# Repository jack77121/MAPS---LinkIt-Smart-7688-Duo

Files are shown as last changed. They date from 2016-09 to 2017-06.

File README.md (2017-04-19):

# Micro Air Pollution Sensing

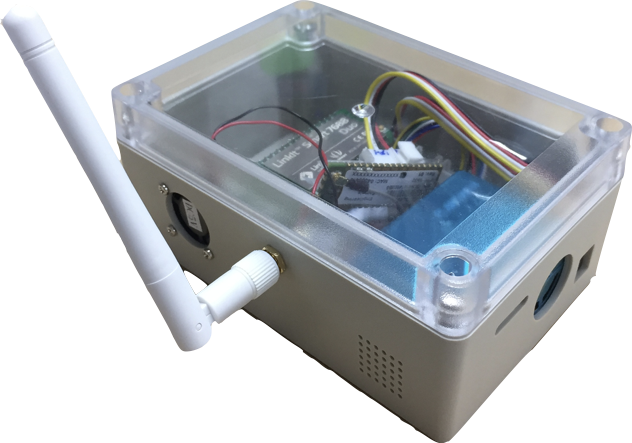
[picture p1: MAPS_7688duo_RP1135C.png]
Image of appearance


MAPS v5.1 appearance

## Story
**M**icro **A**ir **P**ollution **S**ensing - MAPS

Air pollution is a hot topic in recent years, especially - **Particulate Matter**. Traditional sensing method, we can only depend on professional sensors/devices, with large volume, heave weight and insanity price.
Thanks to the technology, now we could build our own air pollution sensing station, with micro volume, light weight and the price is affordable :). With MAPS, you can sense air pollution any where, any time by yourself, you can also give it a battery module to increase its mobility!

For more air pollution sensing project, you can visit [LASS facebook](https://www.facebook.com/groups/1607718702812067/) and [LASS github](https://github.com/LinkItONEDevGroup/LASS), we are makers who sense anything in our environment!

## Hardware & Sensors
Module     			 |	Description
---------------------|--------------
LinkIt Smart 7688 Duo|Mainboard
G5 (pms5003)			 |Particalute matter (PM)
BME280       			 |Temperature, humidity & Air pressure
SHT25					 |Temperature & humidity (optional)

p.s SHT25 is for device temperature, humidity monitoring and future calibration usage, MAPS is be still full functional without it.

## PCB layout & dimensions
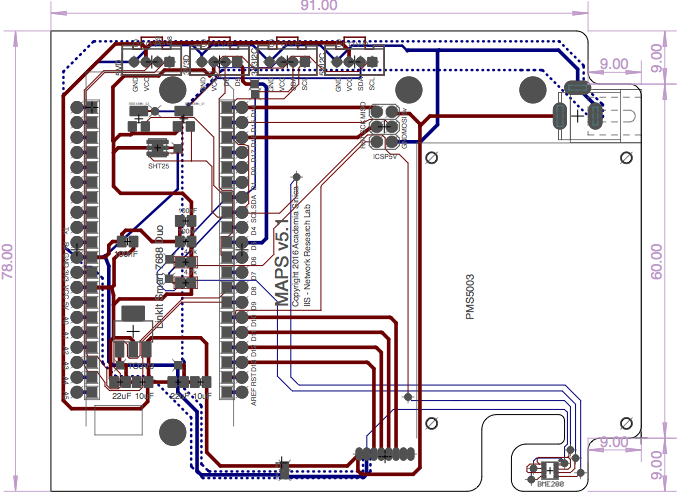
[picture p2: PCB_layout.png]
Image of pcb layout


(unit: mm)

## Installing
### Instrution
MAPS use both MT7688AN (MPU) and ATmega32U4 (MCU) onboard to complete its jobs. They communicate through UART (in this project). 

ATmega32U4 is reponsible for sensors data collection.( and data boardcasting through LPWAN, if you use LoRa.)

There is an OpenWrt Linux OS running on 7688 duo, so MT7688AN is capable for multiple jobs, its main task is data publishing through MQTT to the backend server, others like time sync, program update OTA and user preference setting (wifi, manual GPS) are its routine.

Installation will have two parts, first part is about the MCU program (arduino), and second part are the scripts for MPU.

p.s scripts for MPU are still in progress, will be update ASAP.

Below is the installing instruction about 
### MCU program (arduino)
1. You can download Arduino IDE [here](https://www.arduino.cc/en/Main/Software).
2. Put all folders in `library` into your arduino `libraries` folder. [Tutorial](https://www.arduino.cc/en/Guide/Libraries#toc5)
3. Use Arduino IDE to upload the code: `linkit_7688_duo_lora.ino`. [Tutorial](https://www.arduino.cc/en/Guide/HowtoUpload)

p.s `linkit_7688_duo_lora.ino` need to be in a same name folder, in this project, called `linkit_7688_duo_lora`. If you don't do let, the Arduino app will still ask you to make one. 

### MPU scripts (python + ash)
(Continue updating...)

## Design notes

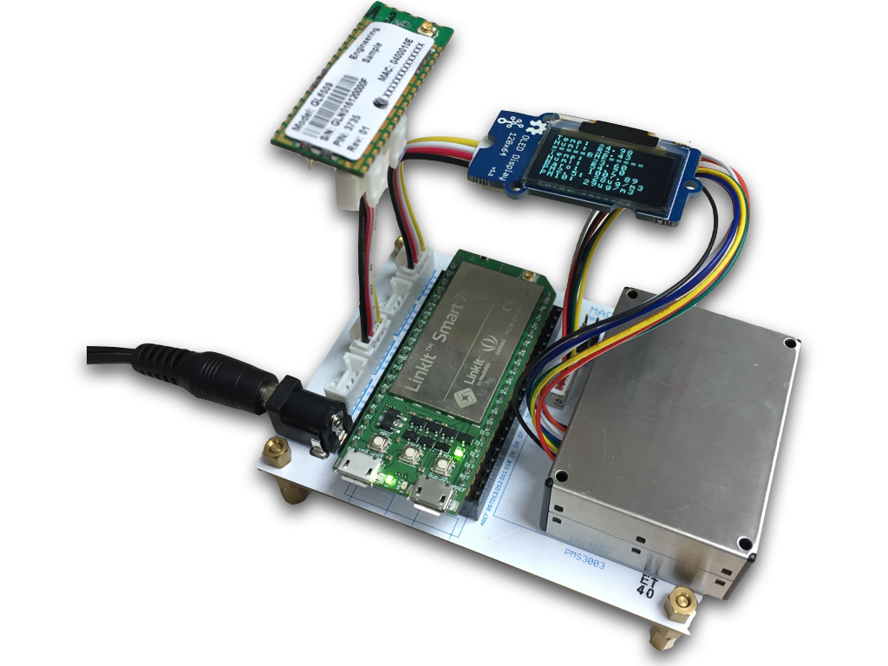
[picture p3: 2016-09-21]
MAPS_7688duo_appearance.png

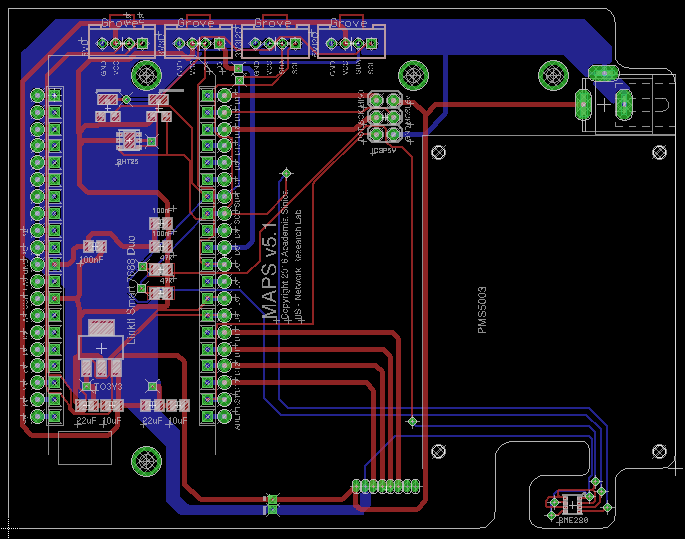
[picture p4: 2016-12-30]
linkit_smart7688_duo_extendboard/maps_board.png

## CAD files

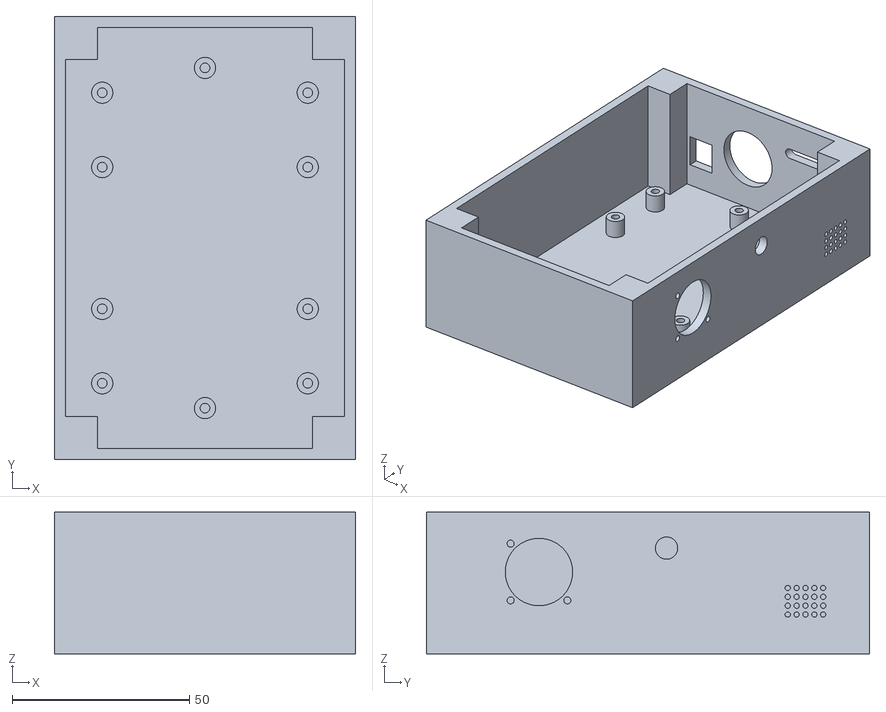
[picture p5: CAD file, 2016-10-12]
linkit_smart7688_duo_extendboard/RP1135C_ piercing_box.stl
85.0 x 125.0 x 40.0

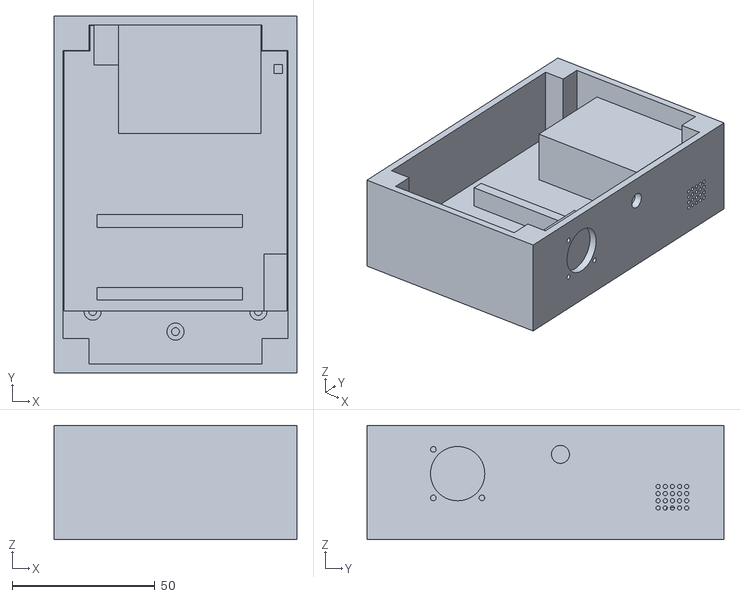
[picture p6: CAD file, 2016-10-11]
linkit_smart7688_duo_extendboard/RP1135C_ piercing.stl
85.0 x 125.0 x 40.0

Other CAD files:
linkit_smart7688_duo_extendboard/RP1135C_ piercing.3dm

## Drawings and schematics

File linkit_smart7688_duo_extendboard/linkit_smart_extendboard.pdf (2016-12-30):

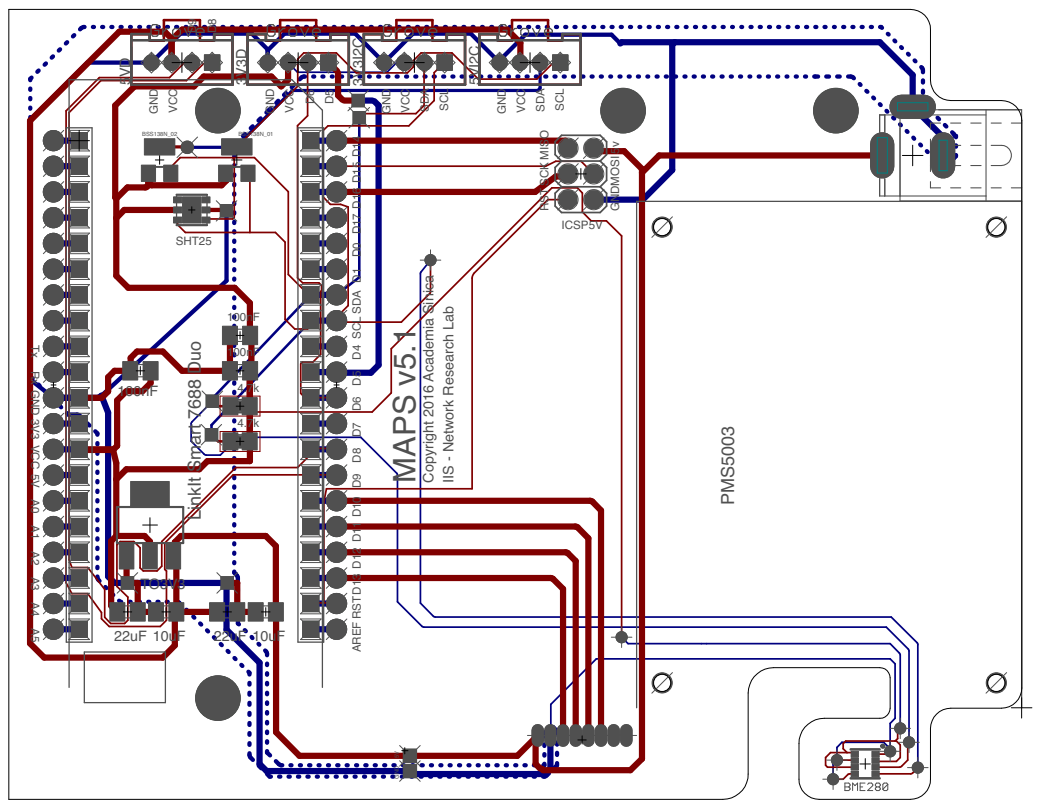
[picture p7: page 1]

VCC GND VCC GND SDA SCL VCC GND VCC GND SDA SCL 5V GND MAPS v5.1 Copyright 2016 Academia Sinica D5 D6 D8 D9 D14 D15 D16 D17 D0 D1 SDA SCL D4 D5 D6 D7 D8 D9 D10 D11 D12 D13 RST AREAF5 A4 A3 A2 A1 A0 5V VCC 3V3 GND Rx Tx 5v MOSI GND RST SCK MISO SHT25 IIS - Network Research Lab 3V3D 3V3I2C 5VD 5VI2C TO3V3 LinkIt Smart 7688 Duo ICSP5V BSS138N_02 BSS138N_01 PMS5003 22uF 10uF 22uF 10uF 100nF 100nF 100nF 4.7k 4.7k

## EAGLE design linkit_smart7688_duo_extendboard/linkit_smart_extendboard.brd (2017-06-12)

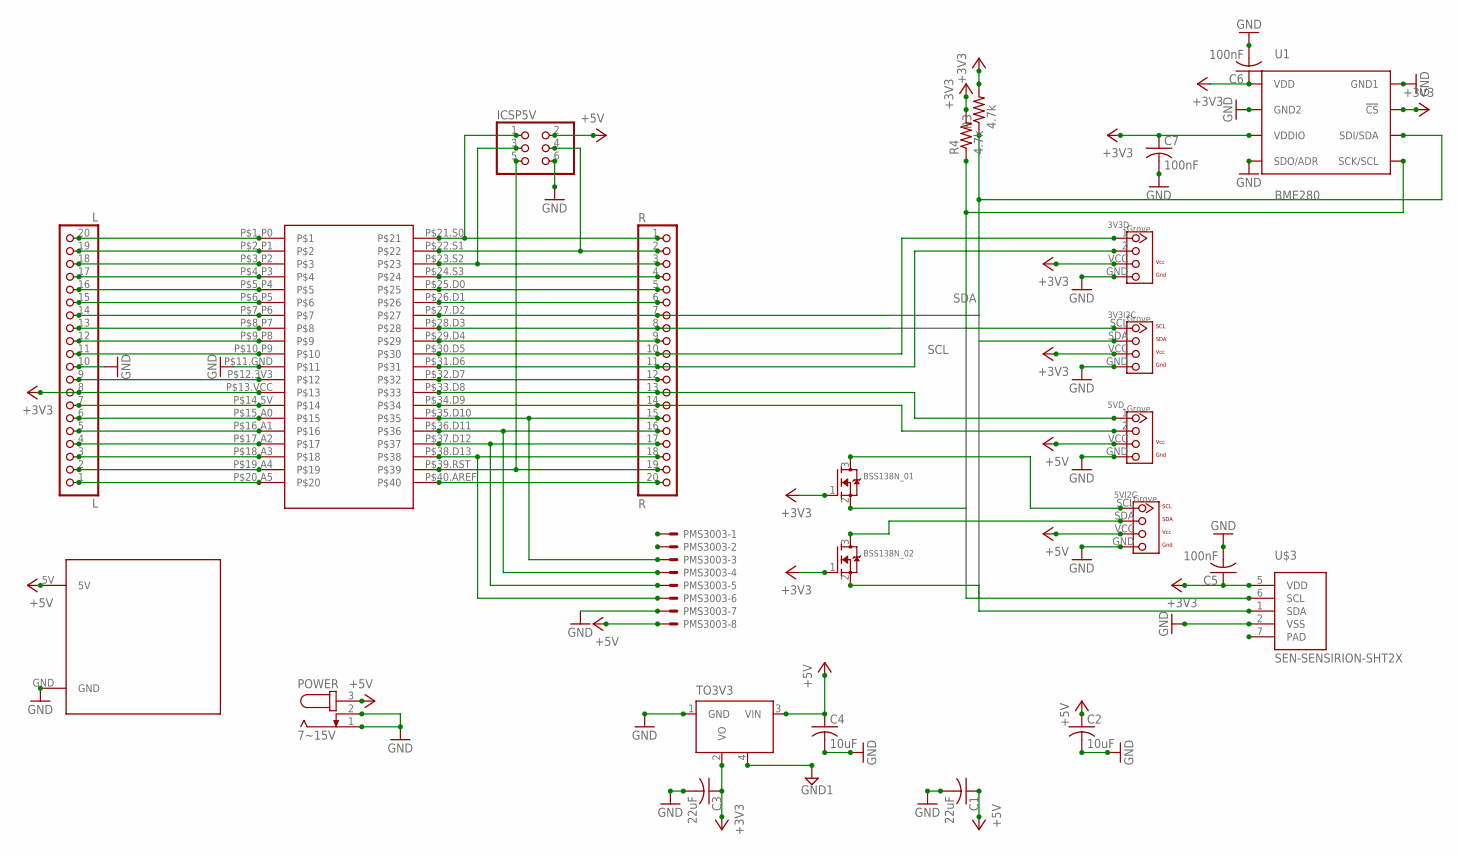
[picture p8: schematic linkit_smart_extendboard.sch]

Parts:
3V3D, 3V3I2C, 5VD, 5VI2C: TWIG-4P-2.0-2.0; 4P-2.0
BSS138N_01, BSS138N_02: MOSFET-NWAVE; SOT23-W
C1, C3: 22uF; C0805K
C2, C4: 10uF; C0805K
C5, C6, C7: 100nF; C0805K
ICSP5V: PINHD-2X3; 2X03
L: L; 1X20-BIG
PMS3003: 53047-08
POWER: 7~15V; SPC4077
R: R; 1X20-BIG
R3, R4: 4.7k; R0805
TO3V3: LM2936MP-3.0; SOT223
U1: BME280; BME280_LGA
U$1: LINKIT7688
U$3: SEN-SENSIRION-SHT2X
U$4: PIN2MM

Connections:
+3V3: 3V3D.VCC (3), 3V3I2C.VCC (3), BSS138N_01.1 (G), BSS138N_02.1 (G), C3.1, C5.1, C6.1, C7.1, L.8, R3.2, R4.2, TO3V3.2 (VO), U1.P$2 (!CS), U1.P$6 (VDDIO), U1.P$8 (VDD), U$1.P$13.VCC, U$3.5 (VDD)
+5V: 5VD.VCC (3), 5VI2C.VCC (3), C1.1, C2.1, C4.1, ICSP5V.2, PMS3003.8, POWER.3, TO3V3.3 (VIN), U$4.5V
GND: 3V3D.GND (4), 3V3I2C.GND (4), 5VD.GND (4), 5VI2C.GND (4), C1.2, C2.2, C3.2, C4.2, C5.2, C6.2, C7.2, ICSP5V.6, L.10, PMS3003.7, POWER.1, POWER.2, TO3V3.1 (GND), U1.P$1 (GND1), U1.P$5 (SDO/ADR), U1.P$7 (GND2), U$1.P$11.GND, U$3.2 (VSS), U$4.GND
GND1: TO3V3.4 (HS)
unnamed: L.9, U$1.P$12.3V3
unnamed: PMS3003.3, R.15, U$1.P$35.D10
unnamed: L.7, U$1.P$14.5V
unnamed: L.6, U$1.P$15.A0
unnamed: L.5, U$1.P$16.A1
unnamed: L.4, U$1.P$17.A2
unnamed: L.3, U$1.P$18.A3
unnamed: L.2, U$1.P$19.A4
unnamed: L.1, U$1.P$20.A5
unnamed: 3V3D.1, R.10, U$1.P$30.D5
unnamed: L.19, U$1.P$2.P1
unnamed: L.18, U$1.P$3.P2
unnamed: L.17, U$1.P$4.P3
unnamed: L.16, U$1.P$5.P4
unnamed: L.15, U$1.P$6.P5
unnamed: L.14, U$1.P$7.P6
unnamed: L.13, U$1.P$8.P7
unnamed: L.12, U$1.P$9.P8
unnamed: L.11, U$1.P$10.P9
unnamed: L.20, U$1.P$1.P0
unnamed: ICSP5V.1, R.1, U$1.P$21.S0
unnamed: ICSP5V.4, R.2, U$1.P$22.S1
unnamed: ICSP5V.3, R.3, U$1.P$23.S2
unnamed: R.4, U$1.P$24.S3
unnamed: R.5, U$1.P$25.D0
unnamed: R.6, U$1.P$26.D1
unnamed: R.9, U$1.P$29.D4
unnamed: R.12, U$1.P$32.D7
unnamed: PMS3003.4, R.16, U$1.P$36.D11
unnamed: 5VD.2, R.14, U$1.P$34.D9
unnamed: 3V3D.2, R.11, U$1.P$31.D6
unnamed: 5VD.1, R.13, U$1.P$33.D8
unnamed: ICSP5V.5, R.19, U$1.P$39.RST
unnamed: PMS3003.6, R.18, U$1.P$38.D13
unnamed: 5VI2C.SCL (1), BSS138N_01.3 (D)
unnamed: R.20, U$1.P$40.AREF
unnamed: PMS3003.5, R.17, U$1.P$37.D12
unnamed: 5VI2C.SDA (2), BSS138N_02.3 (D)
SCL: 3V3I2C.SCL (1), BSS138N_01.2 (S), R.8, R4.1, U1.P$4 (SCK/SCL), U$1.P$28.D3, U$3.6 (SCL)
SDA: 3V3I2C.SDA (2), BSS138N_02.2 (S), R.7, R3.1, U1.P$3 (SDI/SDA), U$1.P$27.D2, U$3.1 (SDA)

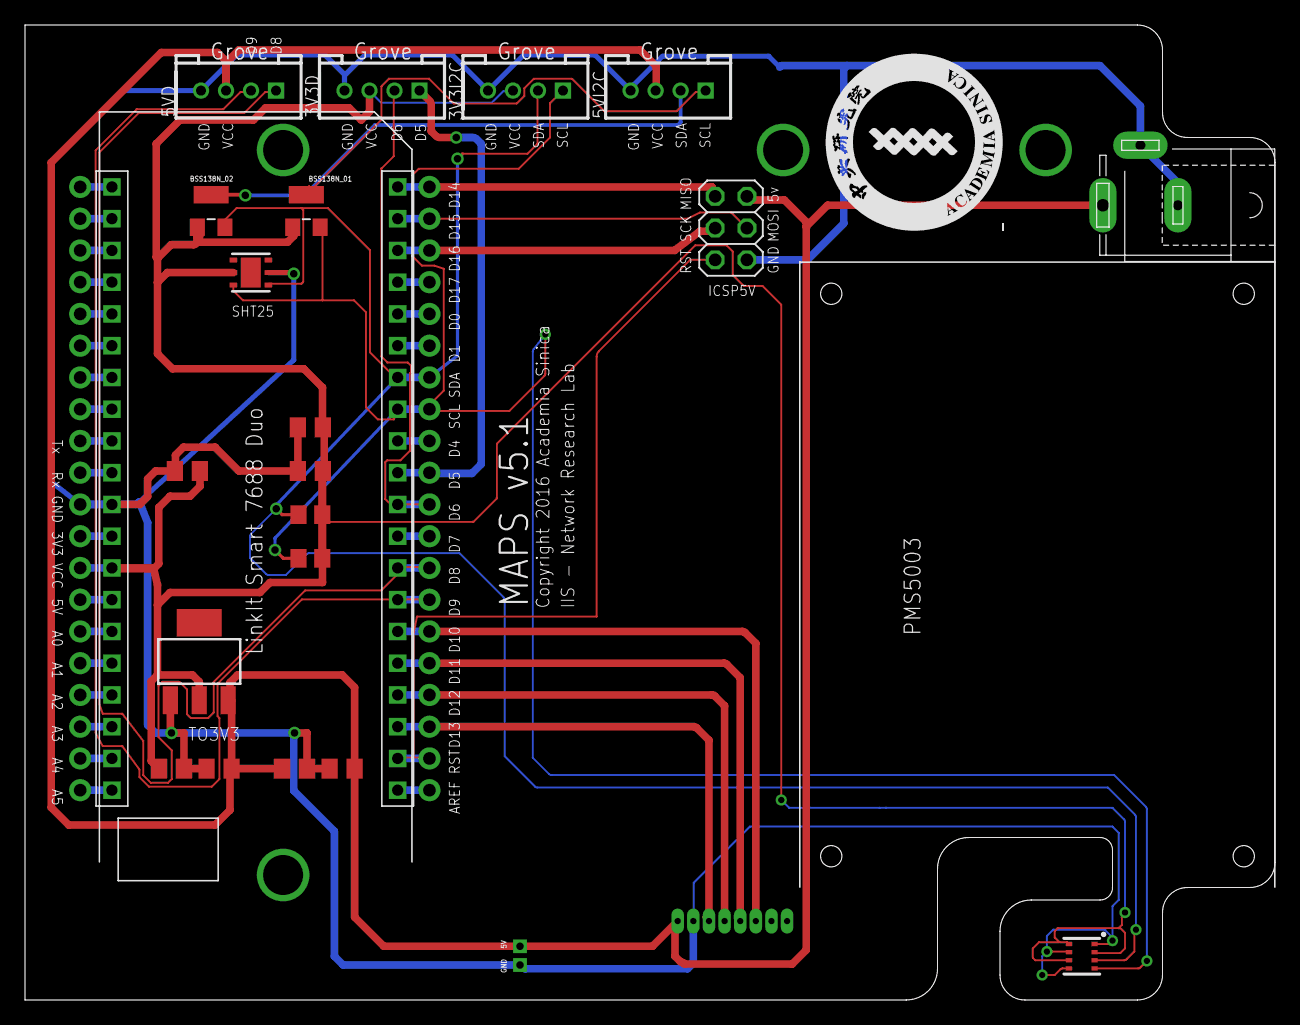
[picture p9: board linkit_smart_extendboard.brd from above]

Board: 2 copper layers, 100.0 x 78.0 mm, 26 parts (0 on the bottom side), 43 nets.

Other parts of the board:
U$2: G5

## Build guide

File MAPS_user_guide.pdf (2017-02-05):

# Micro Air Pollution Sensing

## User guide

Hu-Cheng, Lee - 16 January 2017

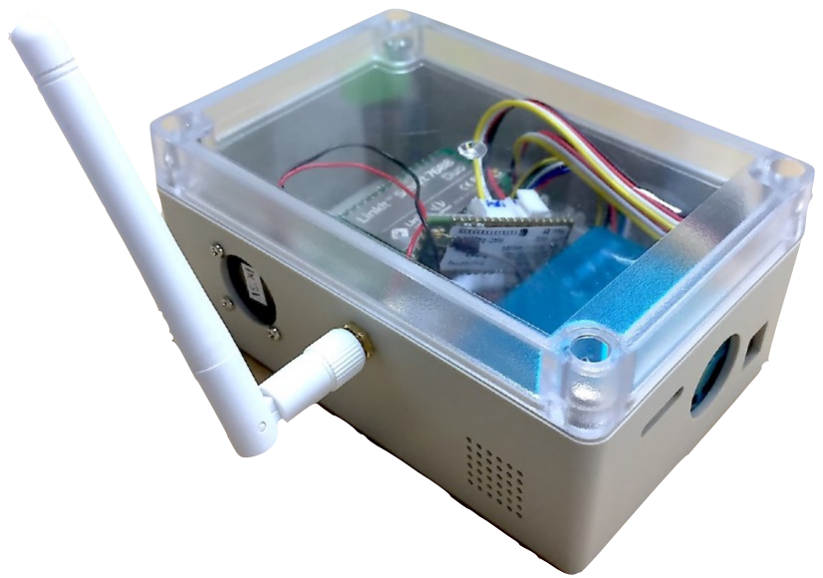
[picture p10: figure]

MAPS USER GUIDE | 1

## Table of Contents

Micro Air Pollution Sensing | 1
User guide | 1
Table of Contents | 2
Set up using browser | 3

## Set up using browser

Step 1.
Power on your MAPS.

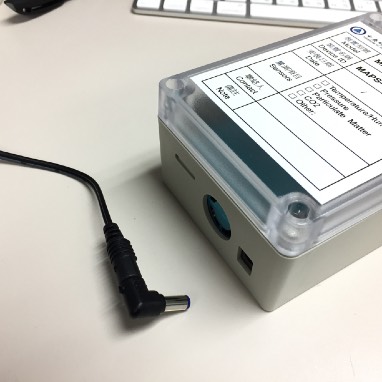
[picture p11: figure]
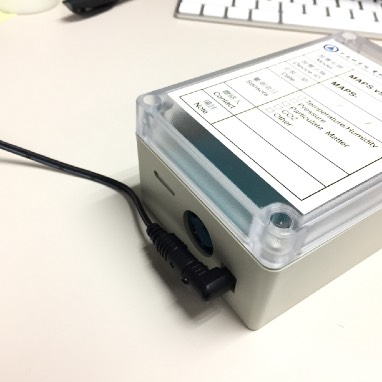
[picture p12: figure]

Connect the power converter to MAPS

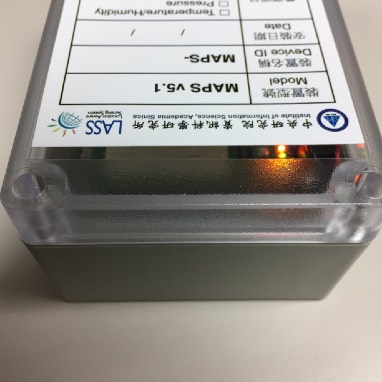
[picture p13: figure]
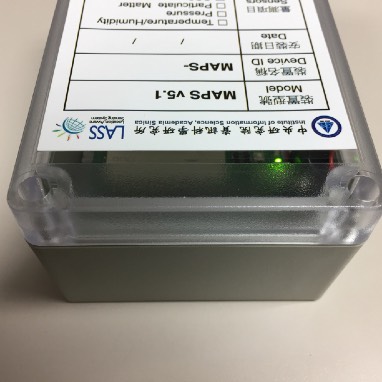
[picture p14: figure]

The red LED will shine for a while, only green LED would keep lighting when MAPS is ready

Step 2.
Open your wifi, find an AP which name begins with “LinkIt_Smart_7688_”, and connect it. You’ll find a red LED on LinkIt Smart start blinking, that means you are doing right.

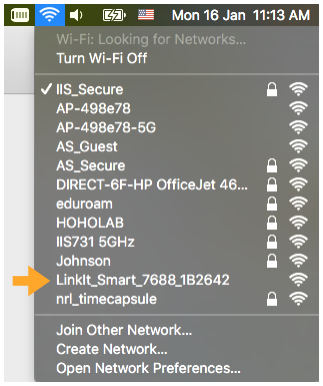
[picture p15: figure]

Step 3.

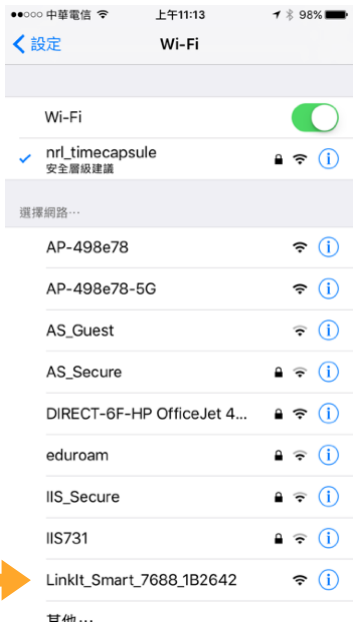
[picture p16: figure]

Open your browser and go to http://mapsoxox.local/cgi-bin/luci
“oxox” is your device id number, you can find it on top of your MAPS.

for example, choose LinkIt_Smart_7688_1B2642, from your laptop or smart phone

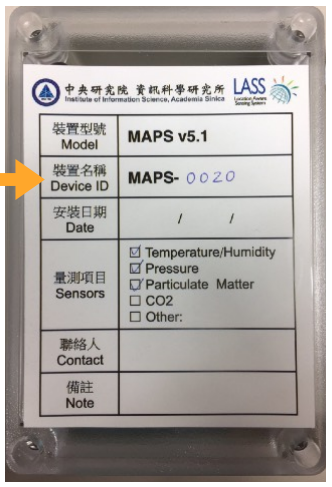
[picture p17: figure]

for example, this device id is MAPS-0020, so go to http://maps0020.local/cgi-bin/luci

Step 4.
Default password is iisnrl619

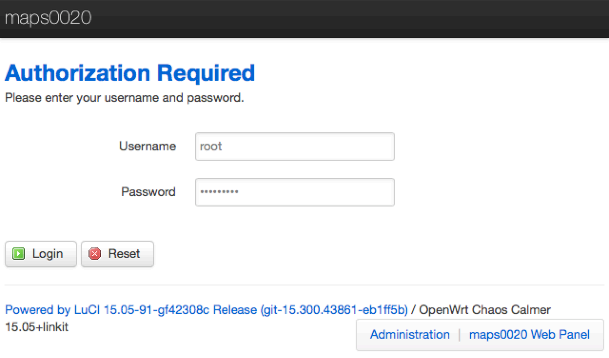
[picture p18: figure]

login

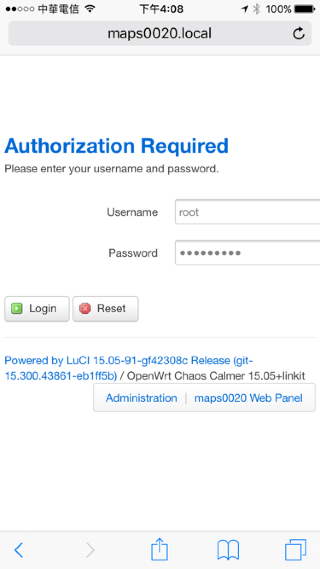
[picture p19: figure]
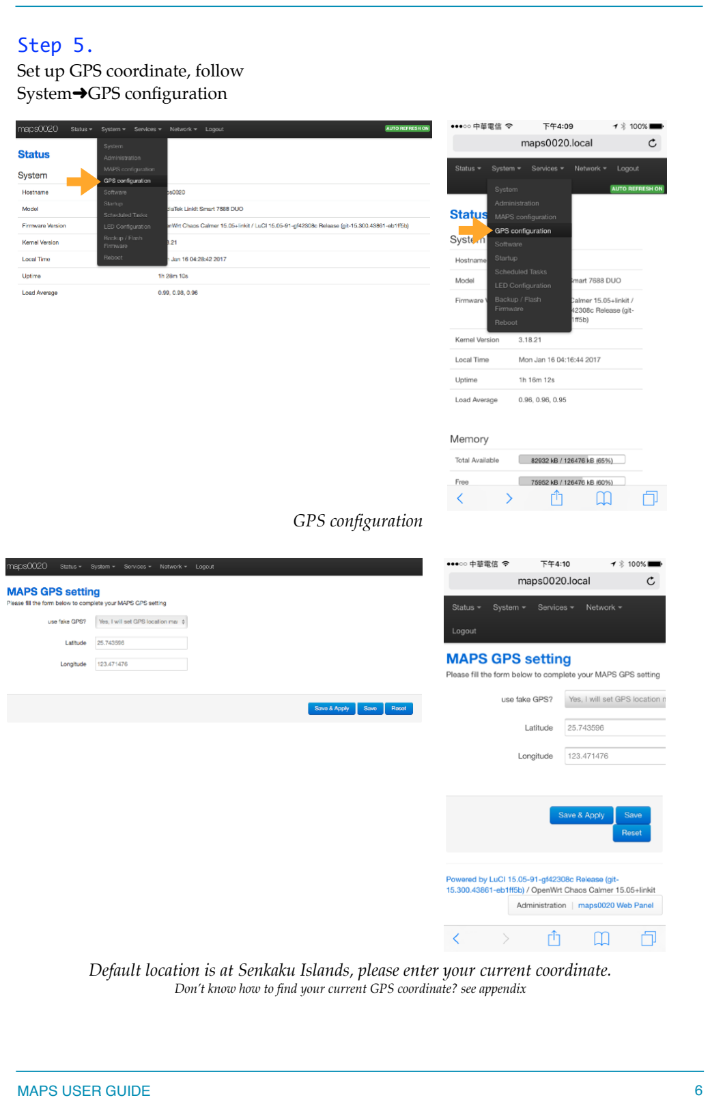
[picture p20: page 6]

Step 5.
Set up GPS coordinate, follow System➜GPS configuration

GPS configuration

Default location is at Senkaku Islands, please enter your current coordinate.
Don’t know how to find your current GPS coordinate? see appendix

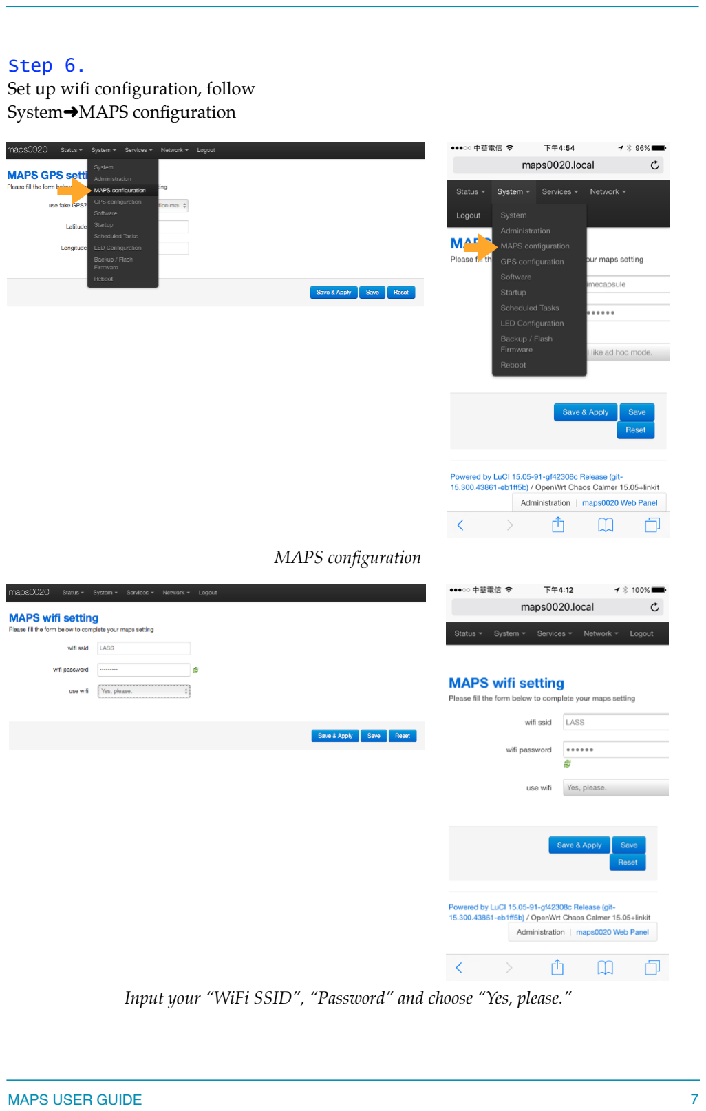
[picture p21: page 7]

Step 6.
Set up wifi configuration, follow System➜MAPS configuration

MAPS configuration

Input your “WiFi SSID”, “Password” and choose “Yes, please.”

Step 7
Your MAPS will reboot after step 6.
Wait about 3 minutes, then your MAPS will start pushing data to the cloud!
Step 8
(find it on the Grafana)

Appendix
(google map, find your location)

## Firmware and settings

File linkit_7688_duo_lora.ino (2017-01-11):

//include library what we need
#include "setting.h"
#include <SoftwareSerial.h>
#define ERROR_VALUE -1

/* * * * * *
 * global variable
 * for sensing target, device temperature & humidity
 * * * * * */	
float g_dev_temperature = 0;
float g_dev_humidity = 0;

/* * * * * *
 * global variable
 * for sensing target, embient temperature, humidity & pressure
 * * * * * */
float g_env_temperature = 0;
float g_env_humidity = 0;
float g_env_baro = 0;

/* * * * * *
 * global variable
 * app id - 
 * 1:
 * 2:
 * 3:
 * 4:
 * 5: for using LinkIt Smart 7688 Duo
 * * * * * */
byte g_app_id = 5;

/* * * * * *
 * global variable
 * for sensing target, PM1, 2.5 & 10
 * * * * * */
int g_pm10 = ERROR_VALUE;	//PM1
int g_pm25 = ERROR_VALUE;	//PM2.5
int g_pm100 = ERROR_VALUE;	//PM10

/* * * * * *
 * global variable
 * GPS value: latitude, longitude & GPS fix #
 * value 15 means fake GPS, change this value to 0 if you using real GPS module
 * * * * * */
char g_GPS_LAT[] = "25.0111";  	// device's gps latitude, IIS NRL, Academia Sinica in DMS format, DD format: 25.041114, DMS format: 25.0228
char g_GPS_LON[] = "121.3256"; 	// device's gps longitude, IIS NRL, Academia Sinica in DMS format, DD format: 121.614444, DMS format: 121.3652
int g_fix_num = 15;				//15 means fake GPS

/* * * * * *
 * global variable
 * Smart 7688 Duo ID and tick after booting
 * * * * * */
String g_dev_id = "0007"; 
unsigned long g_boot_tick;

#if DEV_TH > 0
	#if DEV_TH == 1
		#include <SHT2x.h>	
	#endif
	float get_Dev_Temperature(){
		#if DEV_TH == 1
			return SHT2x.GetTemperature();
		#endif
	}
	float get_Dev_Humidity(){
		#if DEV_TH == 1
			return SHT2x.GetHumidity();
		#endif
	}
#endif

#if SENSE_BAROMETER > 0 or SENSE_TH > 0
	#if SENSE_BAROMETER == 1 or SENSE_TH == 1
		#include <Adafruit_BME280.h>	//our bme280, using i2c//our bme280, using i2c
		#define SEALEVELPRESSURE_HPA (1013.25)	//define sea level embient pressure//define sea level embient pressure
		Adafruit_BME280 bme;
	#endif
	void init_Sensor_Baro(){
		#if SENSE_BAROMETER == 1
			bme.begin();
		#endif
	}
	void init_Sensor_TH(){
		#if SENSE_TH == 1
			bme.begin();
		#endif	
	}
	float get_Env_Pressure(){
		#if SENSE_BAROMETER ==1
			return bme.readPressure() / 100.0F;
		#endif
	}
	float get_Env_Temperature(){
		#if SENSE_TH ==1
			return bme.readTemperature();
		#endif
	}
	float get_Env_Humidity(){
		#if SENSE_TH ==1
			return bme.readHumidity();
		#endif
	}
	

	
#endif


#if SENSE_PM > 0
	#if SENSE_PM == 1 or SENSE_PM == 2
		#define PM_SENSOR_RX 11
		#define PM_SENSOR_TX 12
		#define CHAR_PRELIM	0x42
		#define PM10_BYTE		10
	    #define PM25_BYTE		12
	    #define PM100_BYTE		14
	    SoftwareSerial mySerial(PM_SENSOR_RX, PM_SENSOR_TX); // RX, TX

		
	    
	#endif 
	#if SENSE_PM == 1
		//our g5 sensor, using software serial
		#define NUM_INCOME_BYTE 24	//fix data length 24 bytes
		#define NUM_DATA_BYTE	22
		#define CHECK_BYTE      22
	#endif
	#if SENSE_PM == 2
		//our g5 sensor, using software serial
		#define NUM_INCOME_BYTE 32	//fix data length 32 bytes
		#define NUM_DATA_BYTE   29
	    #define CHECK_BYTE		30

		#define pmsDataLen 32	//fix data length 32 bytes
		uint8_t serialBuf[pmsDataLen];
	    
	#endif
	void init_Sensor_PM(){
	    #if SENSE_PM == 1
	      // do something you want to do
	    #elif SENSE_PM == 2
	      // do something you want to do 
//			mySerial.begin(9600);
			pinMode(10, INPUT);
			pinMode(13, INPUT);	
	    #elif SENSE_PM == 3
	      // do something you want to do 
	    #elif SENSE_PM == 4
	      // do something you want to do 
	    #elif SENSE_PMPM == 5
	      // do something you want to do
	    #elif SENSE_PM == 6
	      // do something you want to do
	    #endif
	    return;
	  }
	void get_Env_PM(int *PM10 = 0, int *PM25 = 0, int *PM100 = 0){
		unsigned long timeout = millis();
	    int count = 0;
	    byte incomeByte[NUM_INCOME_BYTE];
	    boolean startcount = false;
	    byte data;
	    mySerial.begin(9600);
	    while (1){
	      if((millis() - timeout) > 3000) {    
	        Serial.println("[SENSOR-ERROR-TIMEOUT]");
	        break;
	      }
	      if(mySerial.available()){
	        data=mySerial.read();
	        if(data==CHAR_PRELIM && !startcount){
	          startcount = true;
	          count++;
	          incomeByte[0]=data;
	        } else if (startcount){
	          count++;
	          incomeByte[count-1]=data;
	          if(count>=NUM_INCOME_BYTE) {break;}
	        }
	      }
	    }
	    mySerial.end();
	    mySerial.flush();
	    unsigned int calcsum = 0; // BM
	    unsigned int exptsum;
	    for(int i = 0; i < 30; i++) {
	      calcsum += (unsigned int)incomeByte[i];
	    }
	  
	    exptsum = ((unsigned int)incomeByte[CHECK_BYTE] << 8) + (unsigned int)incomeByte[CHECK_BYTE+1];
	    if(calcsum == exptsum) {
	      *PM10 = ((unsigned int)incomeByte[PM10_BYTE] << 8) + (unsigned int)incomeByte[PM10_BYTE+1];
	      *PM25 = ((unsigned int)incomeByte[PM25_BYTE] << 8) + (unsigned int)incomeByte[PM25_BYTE+1];
	      *PM100 = ((unsigned int)incomeByte[PM100_BYTE] << 8) + (unsigned int)incomeByte[PM100_BYTE+1];
	    } else {
	      Serial.println("#[exception] PM2.5 Sensor CHECKSUM ERROR!");
	      *PM10 = ERROR_VALUE;
	      *PM25 = ERROR_VALUE;
	      *PM100 = ERROR_VALUE;
	    }	
	}
#endif
#if OUTPUT_LED > 0
	#if OUTPUT_LED == 1
		#include <SeeedOLED.h>
	#endif
	void init_OLED(){
		#if OUTPUT_LED == 1
			//SeeedOled setting
			SeeedOled.init();  //initialze SEEED OLED display
			DDRB|=0x21;        //digital pin 8, LED glow indicates Film properly Connected .
			PORTB |= 0x21;
			SeeedOled.clearDisplay();          //clear the screen and set start position to top left corner
			SeeedOled.setNormalDisplay();      //Set display to normal mode (i.e non-inverse mode)
			SeeedOled.setPageMode();           //Set addressing mode to Page Mode
			delay(100); 
		#endif
	}
	void ShowOLED(){
		#if OUTPUT_LED == 1
			SeeedOled.setTextXY(0,0);          //Set the cursor to Xth Page, Yth Column
			SeeedOled.putString("Temp: "); //Print the String
			SeeedOled.putFloat(g_dev_temperature); 
			SeeedOled.setTextXY(1,0);          //Set the cursor to Xth Page, Yth Column
			SeeedOled.putString("Humi: "); //Print the String
			SeeedOled.putFloat(g_dev_humidity);
			SeeedOled.setTextXY(2,0);          //Set the cursor to Xth Page, Yth Column
			SeeedOled.putString("=====BME====="); //Print the String
			SeeedOled.setTextXY(3,0);          //Set the cursor to Xth Page, Yth Column
			SeeedOled.putString("Temp: "); //Print the String
			SeeedOled.putFloat(g_env_temperature); 
			SeeedOled.setTextXY(4,0);          //Set the cursor to Xth Page, Yth Column
			SeeedOled.putString("Humi: "); //Print the String
			SeeedOled.putFloat(g_env_humidity);
			SeeedOled.setTextXY(5,0);          //Set the cursor to Xth Page, Yth Column
			SeeedOled.putString("Baro: "); //Print the String
			SeeedOled.putFloat(g_env_baro);
			SeeedOled.setTextXY(6,0);          //Set the cursor to Xth Page, Yth Column
			SeeedOled.putString("PM2.5: "); //Print the String
			SeeedOled.putNumber(g_pm25);
			SeeedOled.putString("ug/m3"); //Print the String
			SeeedOled.setTextXY(7,0);          //Set the cursor to Xth Page, Yth Column
			SeeedOled.putString("PM10: "); //Print the String
			SeeedOled.putNumber(g_pm100);
			SeeedOled.putString("ug/m3"); //Print the String
		#endif	
	}
#endif

#if GPS_USE > 0
	#if GPS_USE == 1
		#include <GPS_FOX1.h>
		GPS_FOX1 gps;
		#define GPS_RX 8
		#define GPS_TX 9
		SoftwareSerial gps(GPS_RX, GPS_TX); //RX, TX
	#endif
	void init_GPS(){
		#if GPS_USE == 1
			gps.begin(9600);	//GPS
		#endif
	}
	void get_GPS(){
		// this function is not completed yet.	
		
		#if GPS_USE == 1
			gps.getGPGGA_GPRMC()
		#endif
	}
	
#endif


#if LORA_USE > 0
	#if LORA_USE == 1
		//our LoRa module, using software serial
		#define LORA_RX 5
		#define LORA_TX 6
		#define LORA_DATA_BYTE_NUM 11
		SoftwareSerial lora(LORA_RX, LORA_TX);	// RX, TX
		byte lora_trans[LORA_DATA_BYTE_NUM];	//lora buffer
		
	#endif
	void init_LoRa(){
		#if LORA_USE == 1
//			lora.begin(9600);	//LoRa
		#endif		
	}
	void LoRaBitMap(byte &app_id, float &temperature, float &humidity, int &pm25, int &pm100, int &fix_num){
		#if LORA_USE == 1
			lora.begin(9600);
			word temperatureLora = (int)((temperature+20)*10);
			word humiditylora = (int)(humidity*10);
			word pm25lora = pm25;
			byte pm100Offset = pm100 - pm25;
			float GPS_LAT_f = (float)atof(g_GPS_LAT);
			float GPS_LON_f = (float)atof(g_GPS_LON);
		//	Serial.println("=====================");
		//	Serial.println(g_GPS_LAT);
		//	Serial.println(g_GPS_LON);
		//	Serial.println(GPS_LAT_f,4);
		//	Serial.println(GPS_LON_f,4);
			
			
			GPS_LAT_f += 90;
			GPS_LON_f += 180;
		//	Serial.println(GPS_LAT_f);
		//	Serial.println(GPS_LON_f);
			unsigned long GPS_LAT_i = GPS_LAT_f*10000;
			unsigned long GPS_LON_i = GPS_LON_f*10000;	
		//	Serial.println(GPS_LAT_i);
		//	Serial.println(GPS_LON_i);
			
			byte lat_D = (int) GPS_LAT_f;
			float temp_lat_M = (GPS_LAT_f - lat_D)*100;
			byte lat_M = (int) temp_lat_M;
			byte lat_S = GPS_LAT_i%100;
			
			
			word lon_D = (int) GPS_LON_f;
			float temp_lon_M = (GPS_LON_f - lon_D)*100;
			byte lon_M = (int) temp_lon_M;
			byte lon_S = GPS_LON_i%100;
			
			byte gps_fix = fix_num;
		
		
			
			lora_trans[0] = (app_id << 4) | (temperatureLora >> 6);	
			lora_trans[1] = (temperatureLora << 2) | (humiditylora >> 8);
			lora_trans[2] = humiditylora;
		
		//	Serial.print(lora_trans[0],HEX);
		//	Serial.print("\t");
		//	Serial.print(lora_trans[1],HEX);
		//	Serial.print("\t");
		//	Serial.print(lora_trans[2],HEX);
		//	Serial.print("\t");
			// END FOR THE APP_ID, TEMPERATURE AND HUMIDITY
		
			
		
			lora_trans[3] =  pm25lora >> 3;
			lora_trans[4] = (pm25lora << 5)|(pm100Offset >> 3);
			
			if(lora_trans[3] < 16){
		//		Serial.print('0');
			}
		//	Serial.print(lora_trans[3],HEX);
		//	Serial.print("\t");
			if(lora_trans[4] < 16){
		//		Serial.print('0');
			}
		//	Serial.print(lora_trans[4],HEX);
		//	Serial.print("\t");
			//END FOR PM2.5 AND PM10	
			
			lora_trans[5] = (pm100Offset <<5) | (lat_D >> 3);
			lora_trans[6] = (lat_D << 5) | (lat_M >> 1);
			lora_trans[7] = (lat_M << 7) | (lat_S << 1) | (lon_D >> 8);
			lora_trans[8] = (byte)lon_D;
			if(lora_trans[5] < 16){
		//		Serial.print('0');
			}
		//	Serial.print(lora_trans[5],HEX);
		//	Serial.print("\t");
		//	Serial.print(lora_trans[6],HEX);
		//	Serial.print("\t");
		//	Serial.print(lora_trans[7],HEX);
		//	Serial.print("\t");
		//	Serial.print(lora_trans[8],HEX);
		//	Serial.print("\t");
		
			lora_trans[9] = (lon_M << 2) | (lon_S >> 4);
			lora_trans[10] = (lon_S << 4) | gps_fix;
		
		//	Serial.print(lora_trans[9],HEX);
		//	Serial.print("\t");
		//	Serial.println(lora_trans[10],HEX);
		
			char buff[33];
			
			sprintf(buff, "AT+DTX=22,%02X%02X%02X%02X%02X%02X%02X%02X%02X%02X%02X\r\n", lora_trans[0], lora_trans[1], \
			lora_trans[2], lora_trans[3], lora_trans[4], lora_trans[5], lora_trans[6], lora_trans[7], lora_trans[8],  \
			lora_trans[9], lora_trans[10]);
			Serial.println(buff);
			
			lora.print(buff);
			lora.end();
			lora.flush();
		//	Serial1.write(buff,33);
		#endif
	}
	
#endif






void setup()
{	
	
	Serial.begin(9600);	//debug serial
	Serial1.begin(57600);	//connect to MT7688

	#if SENSE_TH > 0
		init_Sensor_TH();
	#endif
	
	#if SENSE_BAROMETER > 0
		init_Sensor_Baro();		
	#endif
	
	#if SENSE_PM > 0
		init_Sensor_PM();
		 
	#endif
	
	#if LORA_USE > 0
		init_LoRa();
	#endif

	#if GPS_USE > 0
		init_GPS();
	#endif
	
	#if OUTPUT_LED > 0
		init_OLED();
	#endif
}

void loop()
{ 	
	unsigned long time;
	time = millis();
	Serial.println(time);
	//get sensor value

	#if DEV_TH > 0
		g_dev_temperature = 0;
		g_dev_humidity = 0;
		g_dev_temperature = get_Dev_Temperature();
		g_dev_humidity = get_Dev_Humidity();
	#endif

	#if SENSE_TH > 0
		g_env_temperature = 0;
		g_env_humidity = 0;
		g_env_temperature = get_Env_Temperature();
		g_env_humidity = get_Env_Humidity();
	#endif

	#if SENSE_BAROMETER > 0
		g_env_baro = 0;
		g_env_baro = get_Env_Pressure();
	#endif

	#if SENSE_PM > 0
		g_pm10 = 0;
		g_pm25 = 0;
		g_pm100 = 0;
		get_Env_PM(&g_pm10, &g_pm25, &g_pm100);
	#endif
	#if GPS_USE > 0
		g_GPS_LAT = 0;
		g_GPS_LON = 0;
		g_fix_num = 0;
		get_GPS(g_GPS_LAT, g_GPS_LON, &g_fix_num);
	#endif

	#if OUTPUT_LED == 1
		ShowOLED();
	#endif

	#if LORA_USE == 1
		LoRaBitMap(g_app_id, g_env_temperature, g_env_humidity, g_pm25, g_pm100, g_fix_num);
	#endif
	
	
	SerialMonitor();

	GetDataToMT7688();
	delay(5000);
}




void SerialMonitor(){
	Serial.print("BME Temperature:\t");
	Serial.println(g_env_temperature);

	Serial.print("BME Humidity:\t\t");
	Serial.println(g_env_humidity);

	Serial.print("BME Barometer:\t\t");
	Serial.println(g_env_baro);

	Serial.print("SHT25 Temperature:\t");
	Serial.println(g_dev_temperature);

	Serial.print("SHT25 Humidity:\t\t");
	Serial.println(g_dev_humidity);

	Serial.print("G5 PM2.5:\t\t");
	Serial.println(g_pm25);

	Serial.print("G5 PM10:\t\t");
	Serial.println(g_pm100);
}
	
void GetDataToMT7688(){
	g_boot_tick = millis();
	String temperature_str = String(g_env_temperature, 2);
	String humidity_str = String(g_env_humidity, 2);
	String baro_str = String(g_env_baro, 2);
	String pm10_str = String(g_pm10);
	String pm25_str = String(g_pm25);
	String pm100_str = String(g_pm100);
	String dev_temperature_str = String(g_dev_temperature, 2);
	String dev_humidity_str = String(g_dev_humidity, 2);
	String g_boot_tick_str = String(g_boot_tick);
	String data_str = "";
	data_str = String("|tick=" + g_boot_tick_str + "|s_t4=" + temperature_str + "|s_h4=" + humidity_str + "|s_b2=" + baro_str + "|s_d2=" + pm10_str + "|s_d0=" + pm25_str + "|s_d1=" + pm100_str + "|d_t5=" + dev_temperature_str + "|d_h5=" + dev_humidity_str + "\n");
	Serial.println("My string to MT7688:");
	Serial.println(data_str);
	Serial1.print(data_str);
}

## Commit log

2016-09-02 add PCB layout image
2016-09-12 add eagle PCB files
    [linkit_smart_extendboard.brd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]
2016-09-12 avoid most of the 90 degree circuit layout
2016-09-13 reduce most of 90 degree circuit layout
    [linkit_smart_extendboard.brd]
2016-09-29 update PCB layout,prepare for future box design
    [linkit_smart_extendboard.brd, linkit_smart_extendboard.sch]
2016-10-03 modify PCB layout to fit the RP1135C box and add RP1135C drafting pdf
    [linkit_smart_extendboard.brd]
2016-10-04 update PCB layout for RP1135C box
    [linkit_smart_extendboard.brd, linkit_smart_extendboard.sch]
2016-10-05 update PCB layout & RP1135C piercing 3D design
    [RP1135C_ piercing.3dm, linkit_smart_extendboard.brd, linkit_smart_extendboard.sch]
2016-10-06 export RP1135C STL
    [RP1135C_ piercing.stl]
2016-10-07 change BME280 position to another side, flip the G5 and change position, change DC position
    [RP1135C_ piercing.3dm, RP1135C_ piercing.stl, linkit_smart_extendboard.brd]
2016-10-12 RP1135C 3D design box only
    [RP1135C_ piercing_box.stl]
2016-10-18 add gitignore, update eagle PCB
    [linkit_smart_extendboard.brd]
2016-10-19 add dimension in 3dm, remove 5v LDO on .brd & sch .file we don't need them any more, because the DC in is already 5v
    [RP1135C_ piercing.3dm, linkit_smart_extendboard.brd, linkit_smart_extendboard.sch]
2016-10-26 push data from arduino to MT7688, and use wifi send MQTT package to the broker
2016-11-01 update G5 checksum & RP1135C box design (more hole for BME280)
    [RP1135C_ piercing.3dm]
2016-11-07 change arduino code format, update screw hole size for G5 on PCB
    [linkit_smart_extendboard.brd]
2016-11-25 update arduino code format
2016-12-02 update arduino code, data string to MCU
2016-12-30 update board-pdf, png, arduino code
2016-12-30 update arduino code
2017-01-11 add newline for string which push to MT7688, for fixing bug that serial readline() might read more than once
    [linkit_7688_duo_lora.ino]
2017-06-12 add sinica logo on PCB
    [linkit_smart_extendboard.brd]
